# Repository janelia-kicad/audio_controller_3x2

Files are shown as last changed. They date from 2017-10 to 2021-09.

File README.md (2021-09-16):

- [Repository Information](#orgaf0de10)
  - [Description](#org4f757df)
- [Images](#org2f2734c)
- [Schematic](#org883ee39)
- [Gerbers](#org9caf1d8)
- [Bill of Materials](#org3ae238b)
  - [PCB Parts](#org8b46f87)
  - [Supplemental Parts](#orgfcb51ff)
  - [Vendor Parts Lists](#org931e373)
- [Supplemental Documentation](#orga858066)
  - [Assembly Instructions](#orgc4d95c2)

# Repository Information

-   **Name:** audio\_controller\_3x2
-   **Version:** 1.2
-   **License:** Open-Source Hardware
-   **URL:** <https://github.com/janelia-kicad/audio_controller_3x2>
-   **Author:** Peter Polidoro
-   **Email:** peter@polidoro.io

## Description

This board plays audio through a pcb mounted speaker and/or external stereo speakers.

# Images

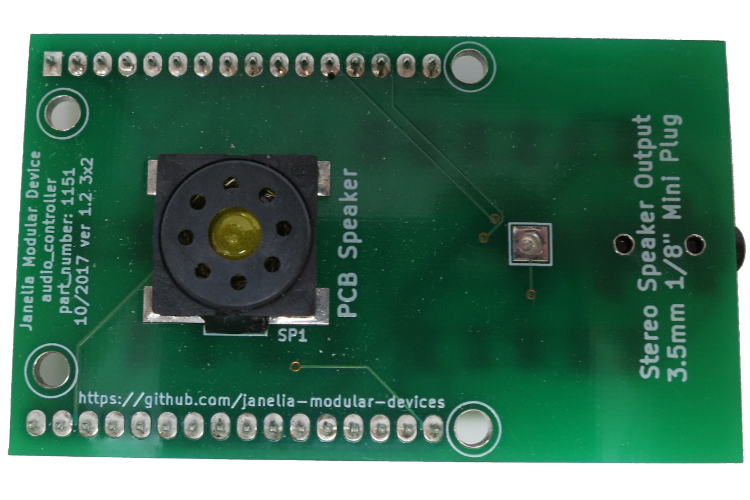
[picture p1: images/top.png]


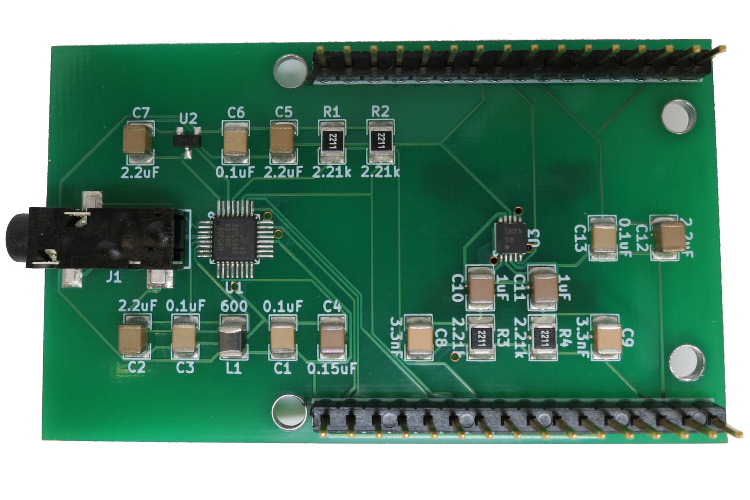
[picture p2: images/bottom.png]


# Schematic

[./schematic/audio\_controller\_3x2.pdf](./schematic/audio_controller_3x2.pdf)

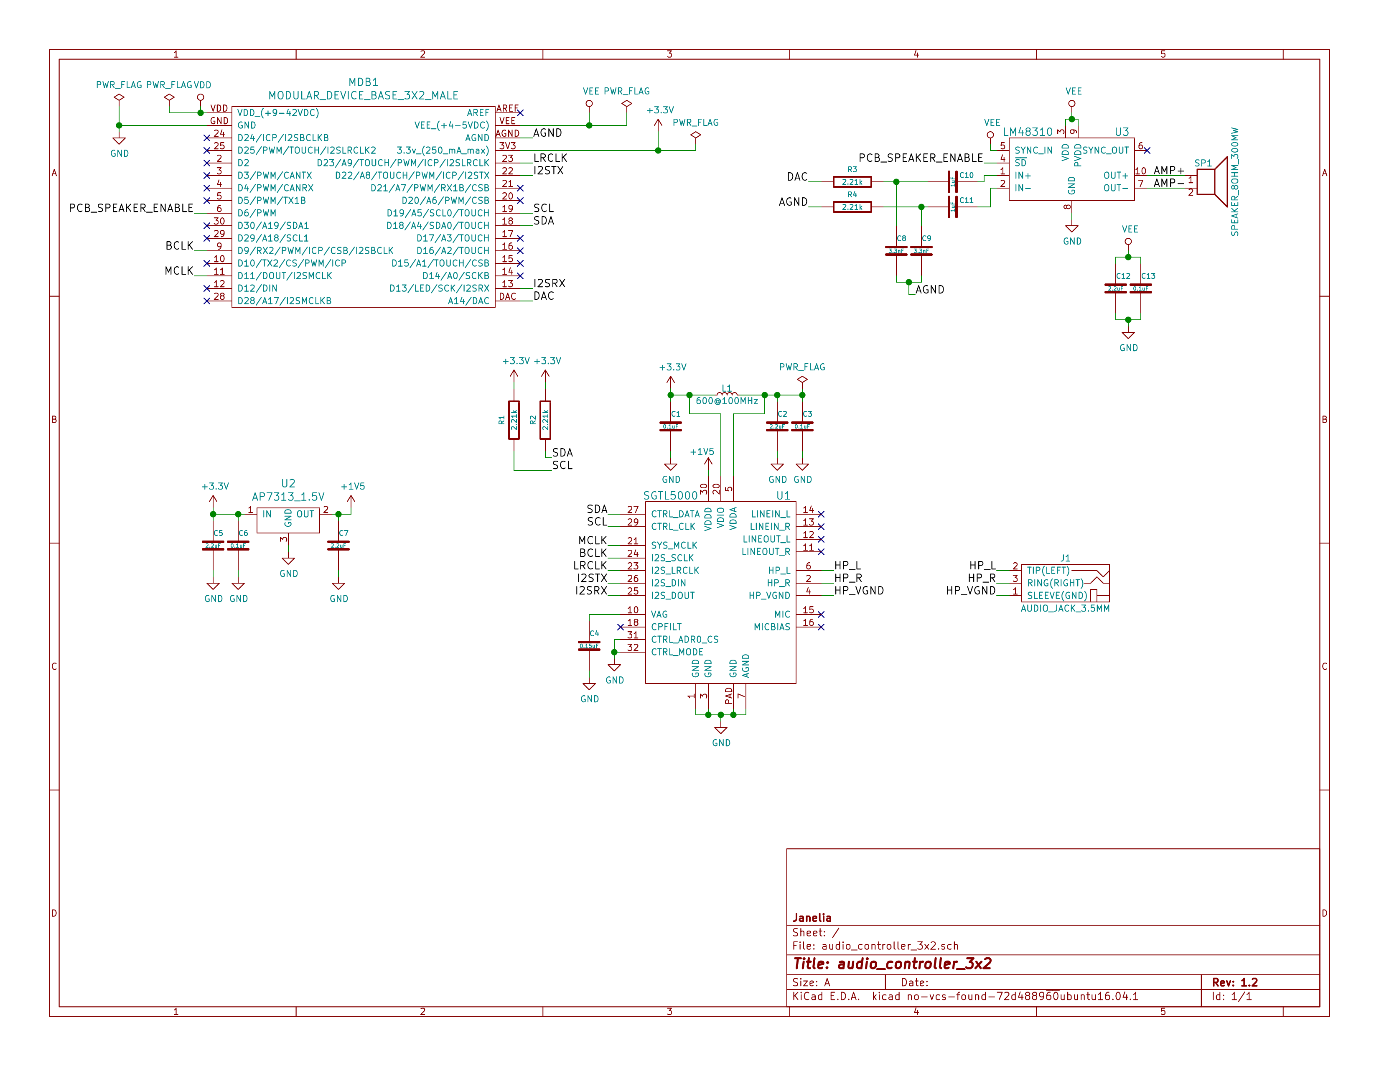
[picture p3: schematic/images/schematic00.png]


# Gerbers

Send gerbers zip file to your favorite PCB manufacturer for fabrication.

[./gerbers/audio\_controller\_3x2\_v1.2.zip](./gerbers/audio_controller_3x2_v1.2.zip)

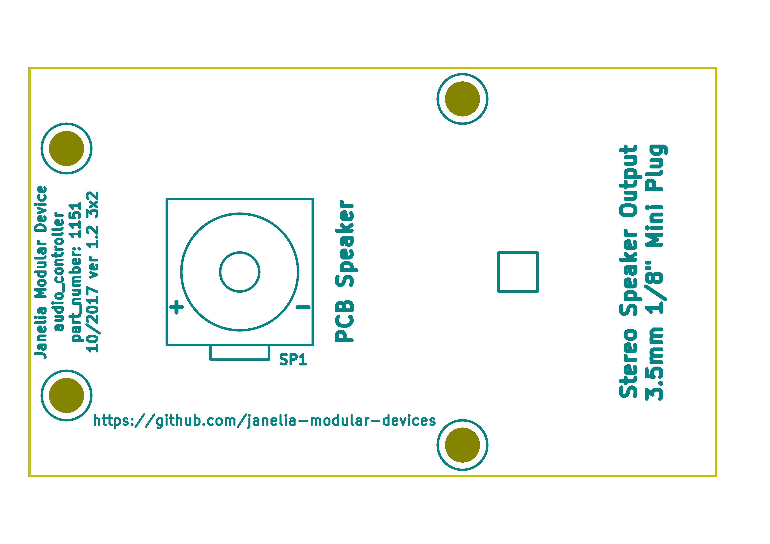
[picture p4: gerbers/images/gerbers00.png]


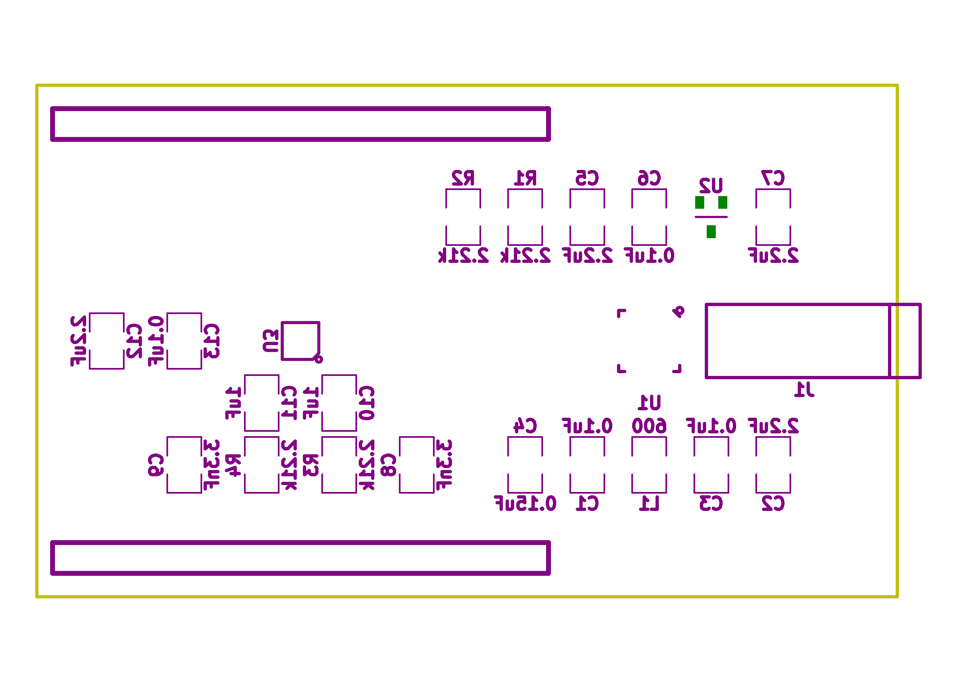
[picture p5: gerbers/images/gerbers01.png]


# Bill of Materials

## PCB Parts

| Item | Reference(s) | Quantity | PartNumber | Vendor  | Description |
|---- |--- |--- |--- |--- |--- |
| 1 | C1 C13 C3 C6 | 4 | 399-13229-1-ND | digikey | CAP CER 0.1UF 100V X7R 1210 |
| 2 | C10 C11 | 2 | 399-8219-1-ND | digikey | CAP CER 1UF 100V X7R 1210 |
| 3 | C12 C2 C5 C7 | 4 | 478-3591-1-ND | digikey | 2.2uF 50V Ceramic Capacitor X7R 1210 |
| 4 | C4 | 1 | 399-15599-1-ND | digikey | 0.15uF 100V Ceramic Capacitor X7R 1210 |
| 5 | C8 C9 | 2 | 478-5964-1-ND | digikey | CAP CER 3300PF 2KV X7R 1210 |
| 6 | J1 | 1 | CP-3523SJCT-ND | digikey | 3.50mm Headphone Phone Jack Stereo Connector Solder |
| 7 | L1 | 1 | 587-1755-1-ND | digikey | FERRITE BEAD 600 OHM 1210 1LN |
| 8 | MDB1 | 2 | S1011E-16-ND | digikey | 16 Position Header Through Hole Male Pins |
| 9 | R1 R2 R3 R4  | 4 | P2.21KAACT-ND | digikey | RES SMD 2.21K OHM 1% 1/2W 1210 |
| 10 | SP1 | 1 | 102-3539-1-ND | digikey | SPEAKER 8OHM 300MW TOP PORT 87DB |
| 11 | U1 | 1 | SGTL5000XNAA3R2CT-ND  | digikey | Stereo Audio Interface 32-QFN |
| 12 | U2 | 1 | AP7313-15SAG-7DICT-ND | digikey | Linear Voltage Regulator IC Positive Fixed 1 Output 1.5V 150mA SOT-23-3 |
| 13 | U3 | 1 | LM48310SD/NOPBCT-ND | digikey | IC AMP AUDIO PWR 2.6W MONO 10SON |

## Supplemental Parts

| Item | Quantity | PartNumber | Vendor | Description |
|---- |--- |--- |--- |--- |
| 1 | 1 | N82E16836121042 | newegg | Logitech Z130 5W Speakers |

## Vendor Parts Lists

[./bom/digikey\_parts.csv](./bom/digikey_parts.csv)

[./bom/supplemental\_newegg\_parts.csv](./bom/supplemental_newegg_parts.csv)

# Supplemental Documentation

## Assembly Instructions

-   Solder surface mount and through hole components onto the pcb.

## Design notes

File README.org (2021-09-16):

# Created 2018-05-18 Fri 09:57
#+OPTIONS: title:nil author:nil email:nil toc:t |:t ^:nil
* Repository Information

- Name :: audio_controller_3x2
- Version :: 1.2
- License :: Open-Source Hardware
- URL :: https://github.com/janelia-kicad/audio_controller_3x2
- Author :: Peter Polidoro
- Email :: peter@polidoro.io

** Description

This board plays audio through a pcb mounted speaker and/or external stereo
speakers.

* Images





* Schematic

[[file:./schematic/audio_controller_3x2.pdf][./schematic/audio_controller_3x2.pdf]]



* Gerbers

Send gerbers zip file to your favorite PCB manufacturer for fabrication.

[[file:./gerbers/audio_controller_3x2_v1.2.zip][./gerbers/audio_controller_3x2_v1.2.zip]]





* Bill of Materials

** PCB Parts

| Item | Reference(s) | Quantity | PartNumber            | Vendor  | Description                                                             |
|------+--------------+----------+-----------------------+---------+-------------------------------------------------------------------------|
|    1 | C1 C13 C3 C6 |        4 | 399-13229-1-ND        | digikey | CAP CER 0.1UF 100V X7R 1210                                             |
|    2 | C10 C11      |        2 | 399-8219-1-ND         | digikey | CAP CER 1UF 100V X7R 1210                                               |
|    3 | C12 C2 C5 C7 |        4 | 478-3591-1-ND         | digikey | 2.2uF 50V Ceramic Capacitor X7R 1210                                    |
|    4 | C4           |        1 | 399-15599-1-ND        | digikey | 0.15uF 100V Ceramic Capacitor X7R 1210                                  |
|    5 | C8 C9        |        2 | 478-5964-1-ND         | digikey | CAP CER 3300PF 2KV X7R 1210                                             |
|    6 | J1           |        1 | CP-3523SJCT-ND        | digikey | 3.50mm Headphone Phone Jack Stereo Connector Solder                     |
|    7 | L1           |        1 | 587-1755-1-ND         | digikey | FERRITE BEAD 600 OHM 1210 1LN                                           |
|    8 | MDB1         |        2 | S1011E-16-ND          | digikey | 16 Position Header Through Hole Male Pins                               |
|    9 | R1 R2 R3 R4  |        4 | P2.21KAACT-ND         | digikey | RES SMD 2.21K OHM 1% 1/2W 1210                                          |
|   10 | SP1          |        1 | 102-3539-1-ND         | digikey | SPEAKER 8OHM 300MW TOP PORT 87DB                                        |
|   11 | U1           |        1 | SGTL5000XNAA3R2CT-ND  | digikey | Stereo Audio Interface 32-QFN                                           |
|   12 | U2           |        1 | AP7313-15SAG-7DICT-ND | digikey | Linear Voltage Regulator IC Positive Fixed 1 Output 1.5V 150mA SOT-23-3 |
|   13 | U3           |        1 | LM48310SD/NOPBCT-ND   | digikey | IC AMP AUDIO PWR 2.6W MONO 10SON                                        |

** Supplemental Parts

| Item | Quantity | PartNumber      | Vendor | Description               |
|------+----------+-----------------+--------+---------------------------|
|    1 |        1 | N82E16836121042 | newegg | Logitech Z130 5W Speakers |

** Vendor Parts Lists

[[file:./bom/digikey_parts.csv][./bom/digikey_parts.csv]]

[[file:./bom/supplemental_newegg_parts.csv][./bom/supplemental_newegg_parts.csv]]

* Supplemental Documentation

** Assembly Instructions

- Solder surface mount and through hole components onto the pcb.

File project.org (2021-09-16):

* Header                                                           :noexport:

  #+MACRO: name audio_controller_3x2
  #+MACRO: version 1.2
  #+MACRO: license Open-Source Hardware
  #+MACRO: url https://github.com/janelia-kicad/audio_controller_3x2
  #+AUTHOR: Peter Polidoro
  #+EMAIL: peter@polidoro.io

* Description

  This board plays audio through a pcb mounted speaker and/or external stereo
  speakers.

* Assembly Instructions

  - Solder surface mount and through hole components onto the pcb.

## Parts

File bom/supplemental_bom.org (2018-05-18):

* Supplemental Bill of Materials
#+RESULTS: supplemental-parts
| Item | Quantity | PartNumber      | Vendor | Description               |
|------+----------+-----------------+--------+---------------------------|
|    1 |        1 | N82E16836121042 | newegg | Logitech Z130 5W Speakers |

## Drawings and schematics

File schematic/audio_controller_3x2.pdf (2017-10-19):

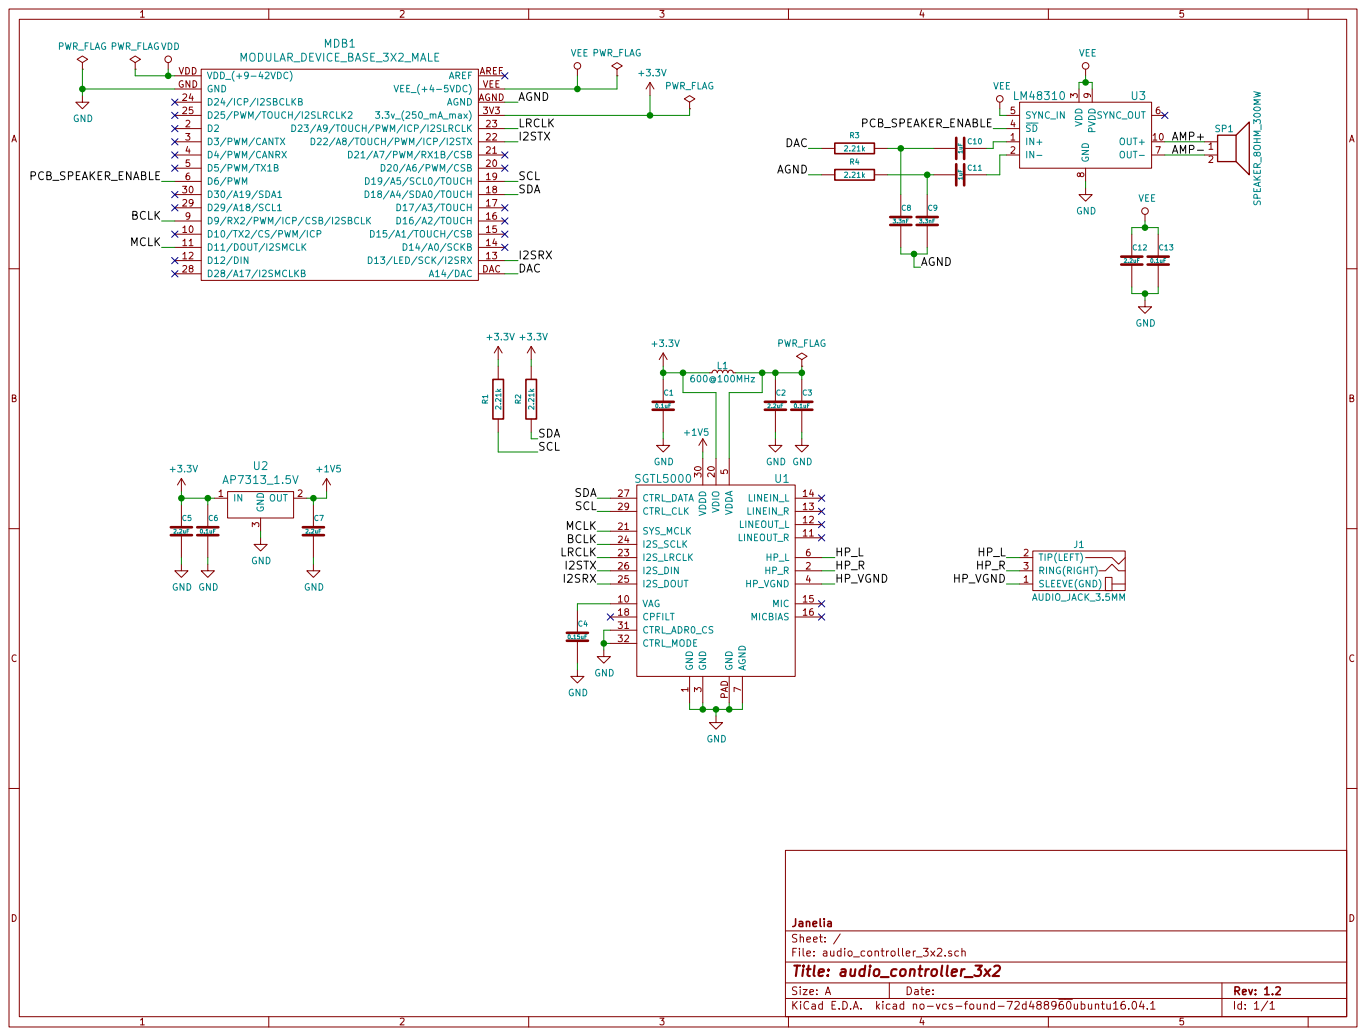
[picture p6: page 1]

File: audio_controller_3x2.sch Sheet: / Janelia

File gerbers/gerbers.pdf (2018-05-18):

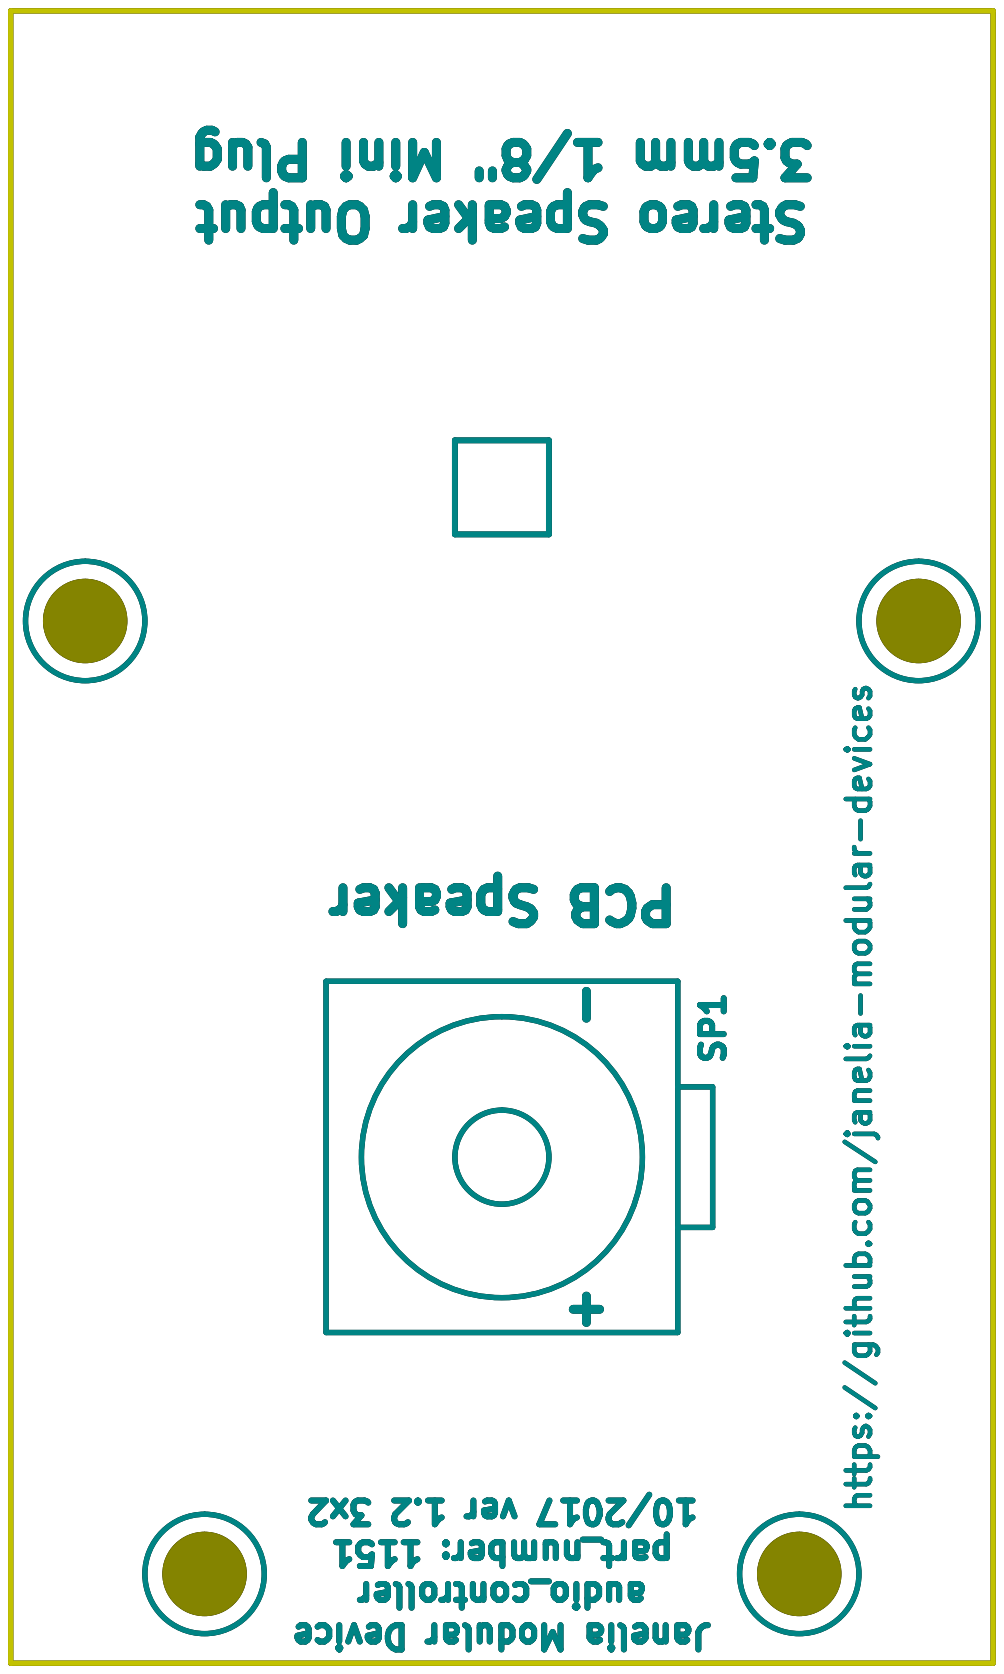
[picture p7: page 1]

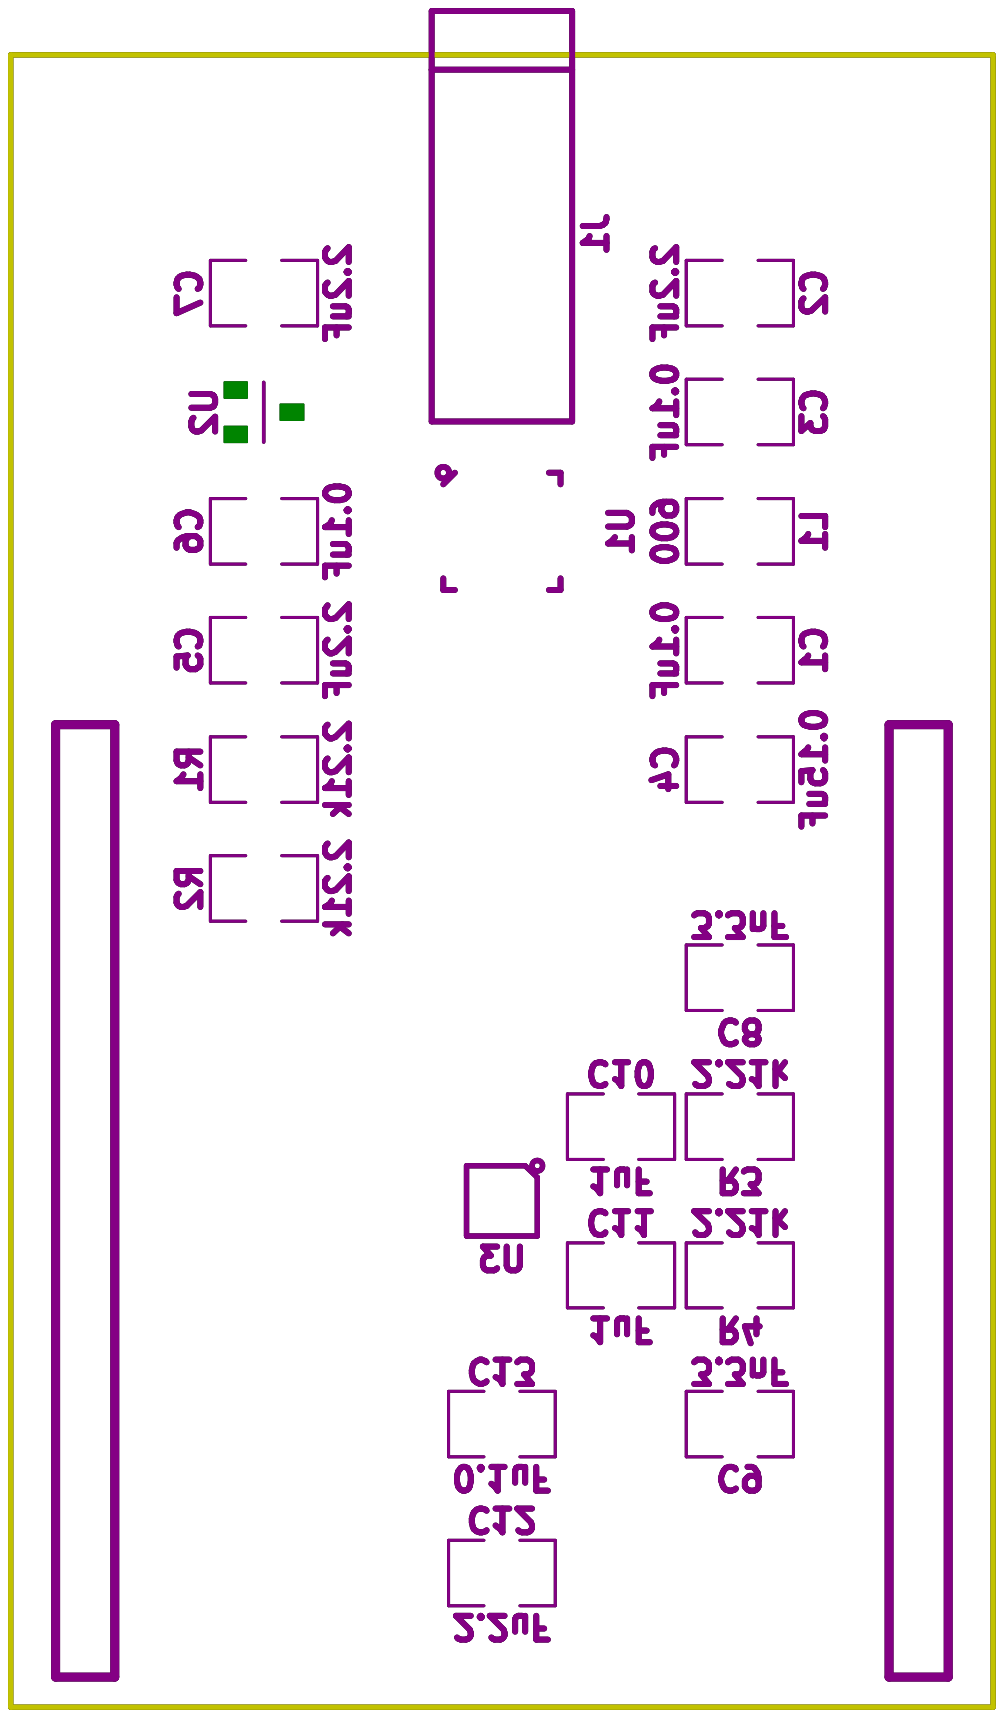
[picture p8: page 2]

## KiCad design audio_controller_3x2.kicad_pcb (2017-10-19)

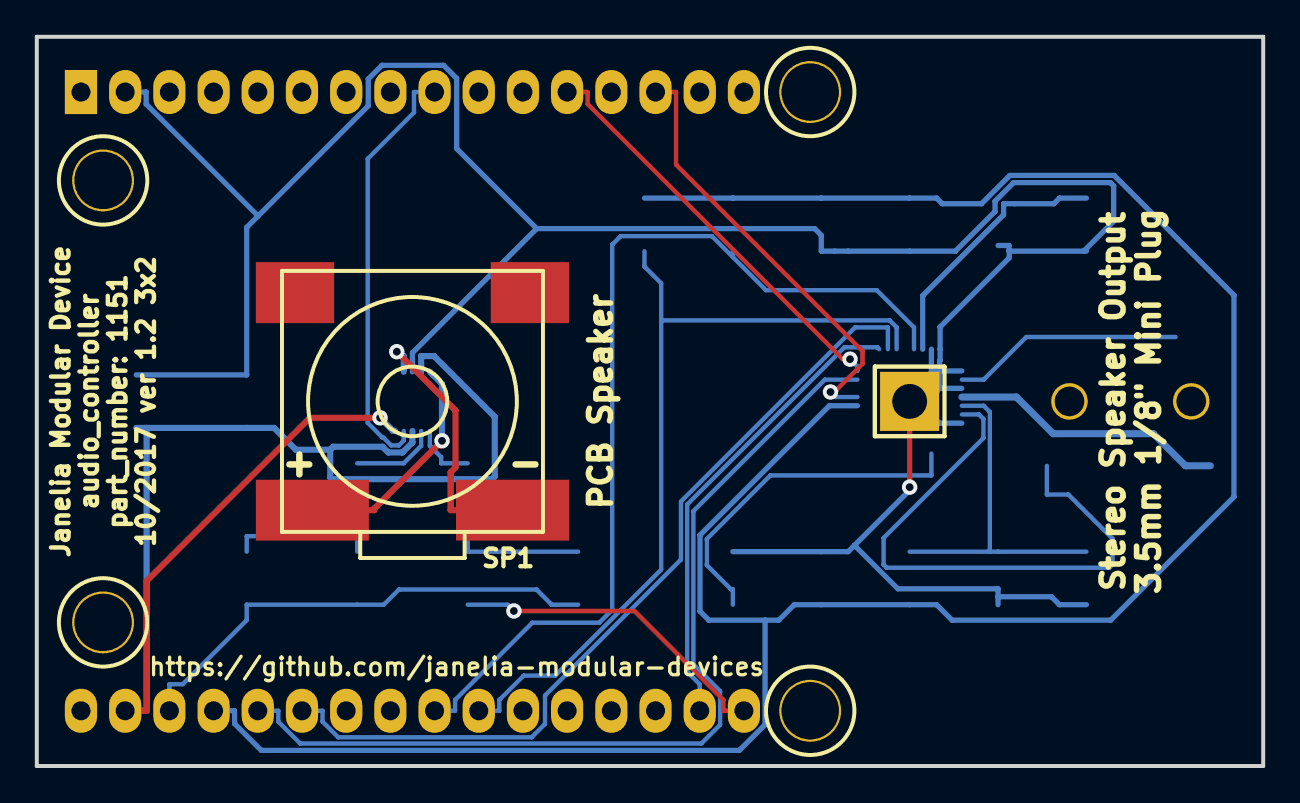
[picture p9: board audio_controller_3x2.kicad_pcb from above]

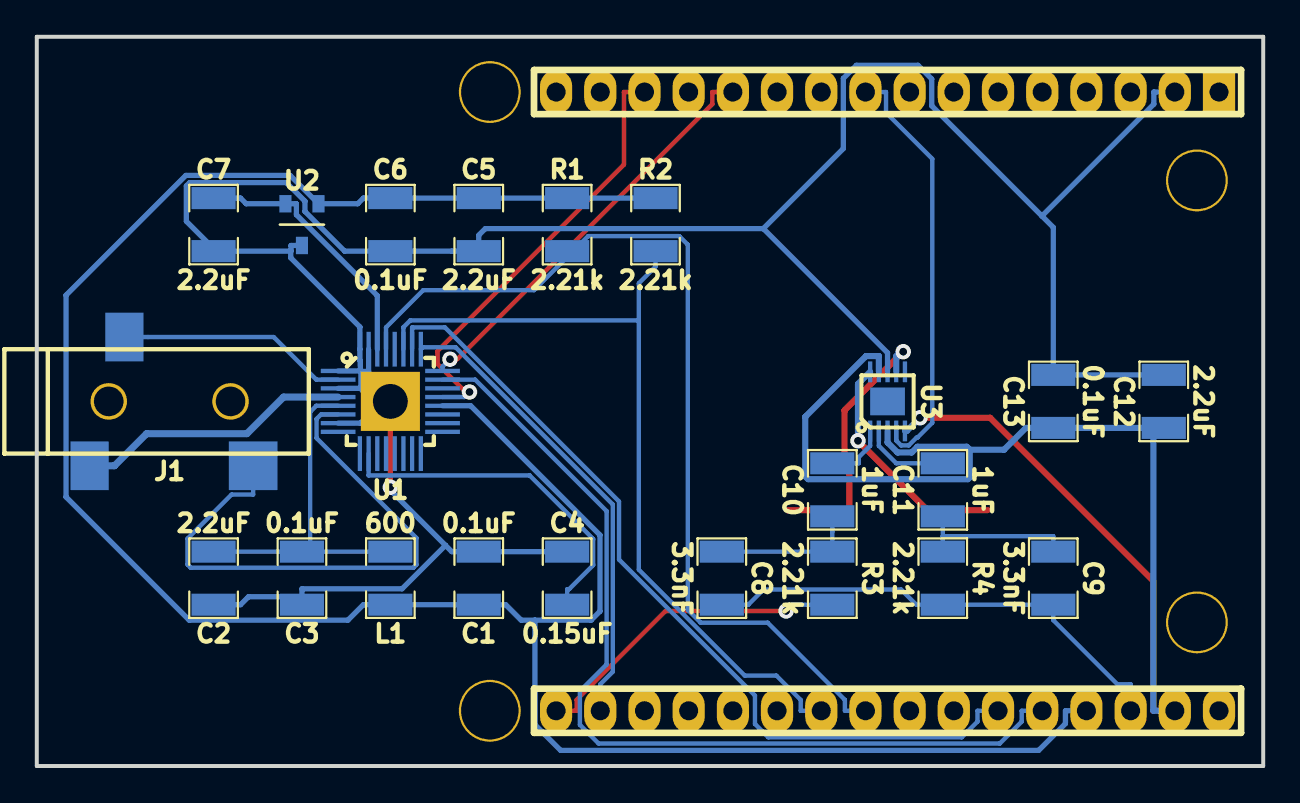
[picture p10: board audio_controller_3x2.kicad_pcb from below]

Board: 2 copper layers, 70.5 x 41.9 mm, 24 parts (22 on the bottom side), 25 nets.

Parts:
C1, C3, C6, C13: 0.1uF; SM1210
C2, C5, C7, C12: 2.2uF; SM1210
C4: 0.15uF; SM1210
C8, C9: 3.3nF; SM1210
C10, C11: 1uF; SM1210
J1: AUDIO_JACK_3.5MM; AUDIO_JACK_3.5MM_3PIN
L1: 600; SM1210
MDB1: MODULAR_DEVICE_BASE_3X2_MALE
R1, R2, R3, R4: 2.21k; SM1210
SP1: SPEAKER_8OHM_300MW
U1: SGTL5000; QFN-5x5-32
U2: AP7313_1.5V; SOT-23-3
U3: LM48310; 10-WFDFN_EXPOSED_PAD

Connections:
+1V5: C7.1, U1.30, U2.2
+3V3: C1.1, C5.1, C6.1, L1.1, MDB1.3V3, R1.1, R2.1, U1.20, U2.1
/AGND: C8.2, C9.2, MDB1.AGND, R4.2
/AMP+: SP1.1, U3.10
/AMP-: SP1.2, U3.7
/BCLK: MDB1.9, U1.24
/DAC: MDB1.DAC, R3.2
/HP_L: J1.2, U1.6
/HP_R: J1.3, U1.2
/HP_VGND: J1.1, U1.4
/I2SRX: MDB1.13, U1.25
/I2STX: MDB1.22, U1.26
/LRCLK: MDB1.23, U1.23
/MCLK: MDB1.11, U1.21
/PCB_SPEAKER_ENABLE: MDB1.6, U3.4
/SCL: MDB1.19, R1.2, U1.29
/SDA: MDB1.18, R2.2, U1.27
GND: C1.2, C2.2, C3.2, C4.2, C5.2, C6.2, C7.2, C12.2, C13.2, MDB1.GND, U1.1, U1.3, U1.7, U1.31, U1.32, U1.PAD, U2.3, U3.8
unnamed: C2.1, C3.1, L1.2, U1.5
unnamed: C4.1, U1.10
unnamed: C8.1, C10.1, R3.1
unnamed: C10.2, U3.1
unnamed: C9.1, C11.1, R4.1
unnamed: C11.2, U3.2
VEE: C12.1, C13.1, MDB1.VEE, U3.3, U3.5, U3.9

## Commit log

2017-03-24 Initial commit.
    [audio_controller_3x2-B.Cu.gbl, audio_controller_3x2-B.Mask.gbs, audio_controller_3x2-B.SilkS.gbo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]
2017-03-24 Progress towards v1.0.
    [audio_controller_3x2.dsn, audio_controller_3x2.kicad_pcb, audio_controller_3x2.sch]
2017-03-27 Finished version 1.0.
    [audio_controller_3x2-B.Cu.gbl, audio_controller_3x2-B.Mask.gbs, audio_controller_3x2-B.SilkS.gbo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]
2017-07-14 Moved edge positions.
    [audio_controller_3x2.kicad_pcb]
2017-09-13 Added SPEAKER_8OHM_300MW.kicad_mod.
2017-09-13 Added LM48310.
    [audio_controller_3x2.kicad_pcb, audio_controller_3x2.sch]
2017-09-13 Updated 0.1uF capacitors.
    [audio_controller_3x2.sch, bom_pcb.csv, digikey_order.csv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]
2017-09-13 Added speaker and amplifier.
    [audio_controller_3x2.kicad_pcb, audio_controller_3x2.sch, bom_pcb.csv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]
2017-09-14 Finished v1.1.
    [audio_controller_3x2-B.Cu.gbl, audio_controller_3x2-B.Mask.gbs, audio_controller_3x2-B.SilkS.gbo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]
2017-09-14 Updated gerber zip file.
2017-10-05 Fixed 0.15uF part number.
    [audio_controller_3x2.sch, bom_pcb.csv, digikey_order.csv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]
2017-10-17 Progress towards v1.2.
    [audio_controller_3x2.dsn, audio_controller_3x2.kicad_pcb, audio_controller_3x2.sch]
2017-10-19 Finished version 1.2.
    [audio_controller_3x2-B.Cu.gbl, audio_controller_3x2-B.Mask.gbs, audio_controller_3x2-B.SilkS.gbo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]
2018-01-08 Updated to v4.
    [audio_controller_3x2.sch]
2018-05-18 Updated documentation.
    [bom_pcb.csv, bom_pcb_add.csv, digikey_order.csv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]
2018-08-12 Marked extra Teensy pins.
2021-09-21 Remove ignored files
    [audio_controller_3x2.dsn]
